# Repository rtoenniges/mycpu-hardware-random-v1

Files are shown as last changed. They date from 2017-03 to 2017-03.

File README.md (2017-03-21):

# MyCPU_HDW_RandomV1
A hardware random number generator for the [MyCPU](http://www.mycpu.eu/) based on the work of [Aaron Logue](http://www.cryogenius.com/hardware/rng/).

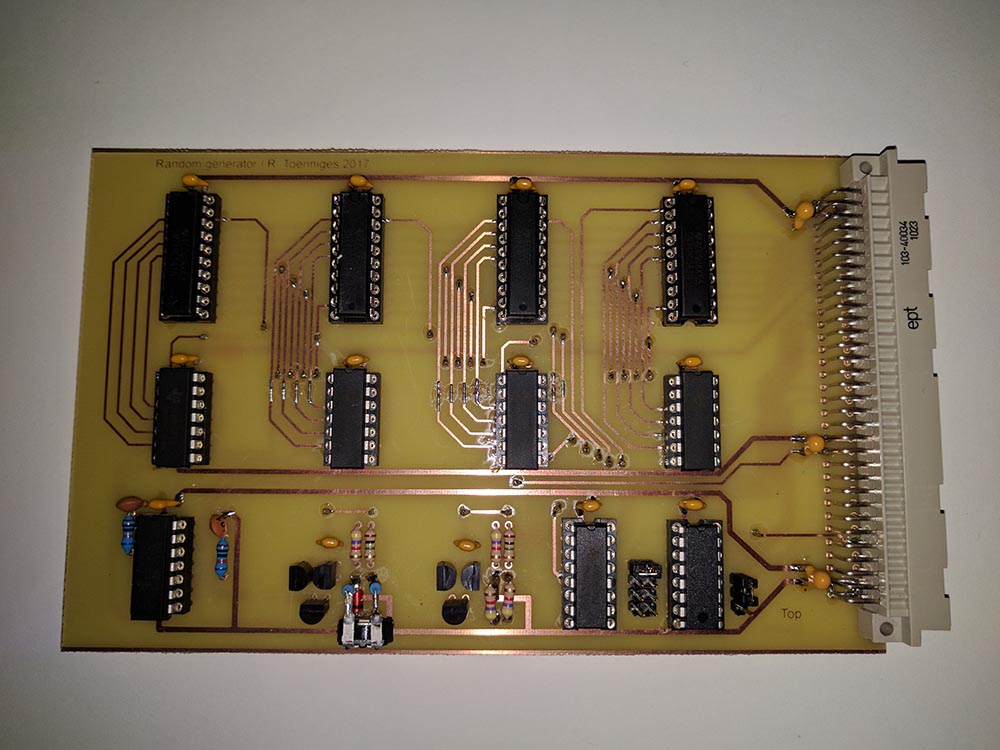
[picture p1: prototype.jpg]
Picture of the prototype The first prototype


## Applications
* Games
* Math programs
* Encryption

## Features
* Address selectable through jumpers
* Two independent noise generators
* Both noise generators were adjustable through trimmers (For justage please use this [software](/hist_prg))
* Generates 2x 16bit random numbers simultaneously
* Fetch frequenz about 1MHz (means a new random number every ~16µs)

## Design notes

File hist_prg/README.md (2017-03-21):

# Software - Random histogram

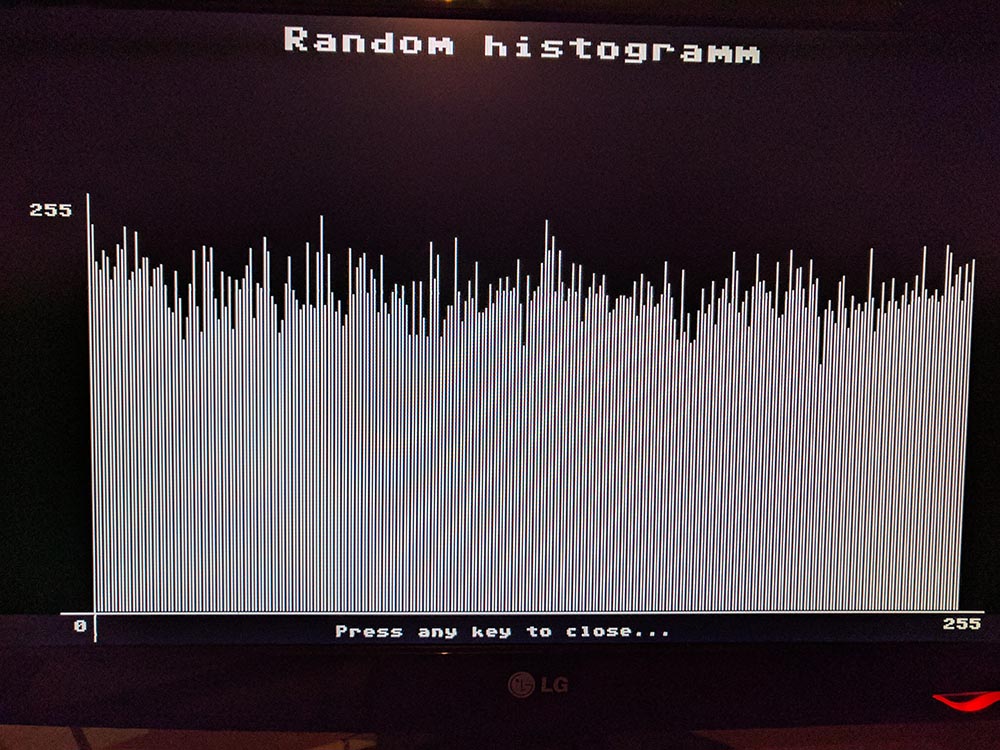
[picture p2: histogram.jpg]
Picture of a histogramm Histogram created by 'random_histo'


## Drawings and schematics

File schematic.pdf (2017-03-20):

# 74HC139N VCC

GND ¹⁰⁰n | 10u 100n 100n 100n 100n 100n 100n 100n 100n 100n 100n | 10u 10u | +12V VCC

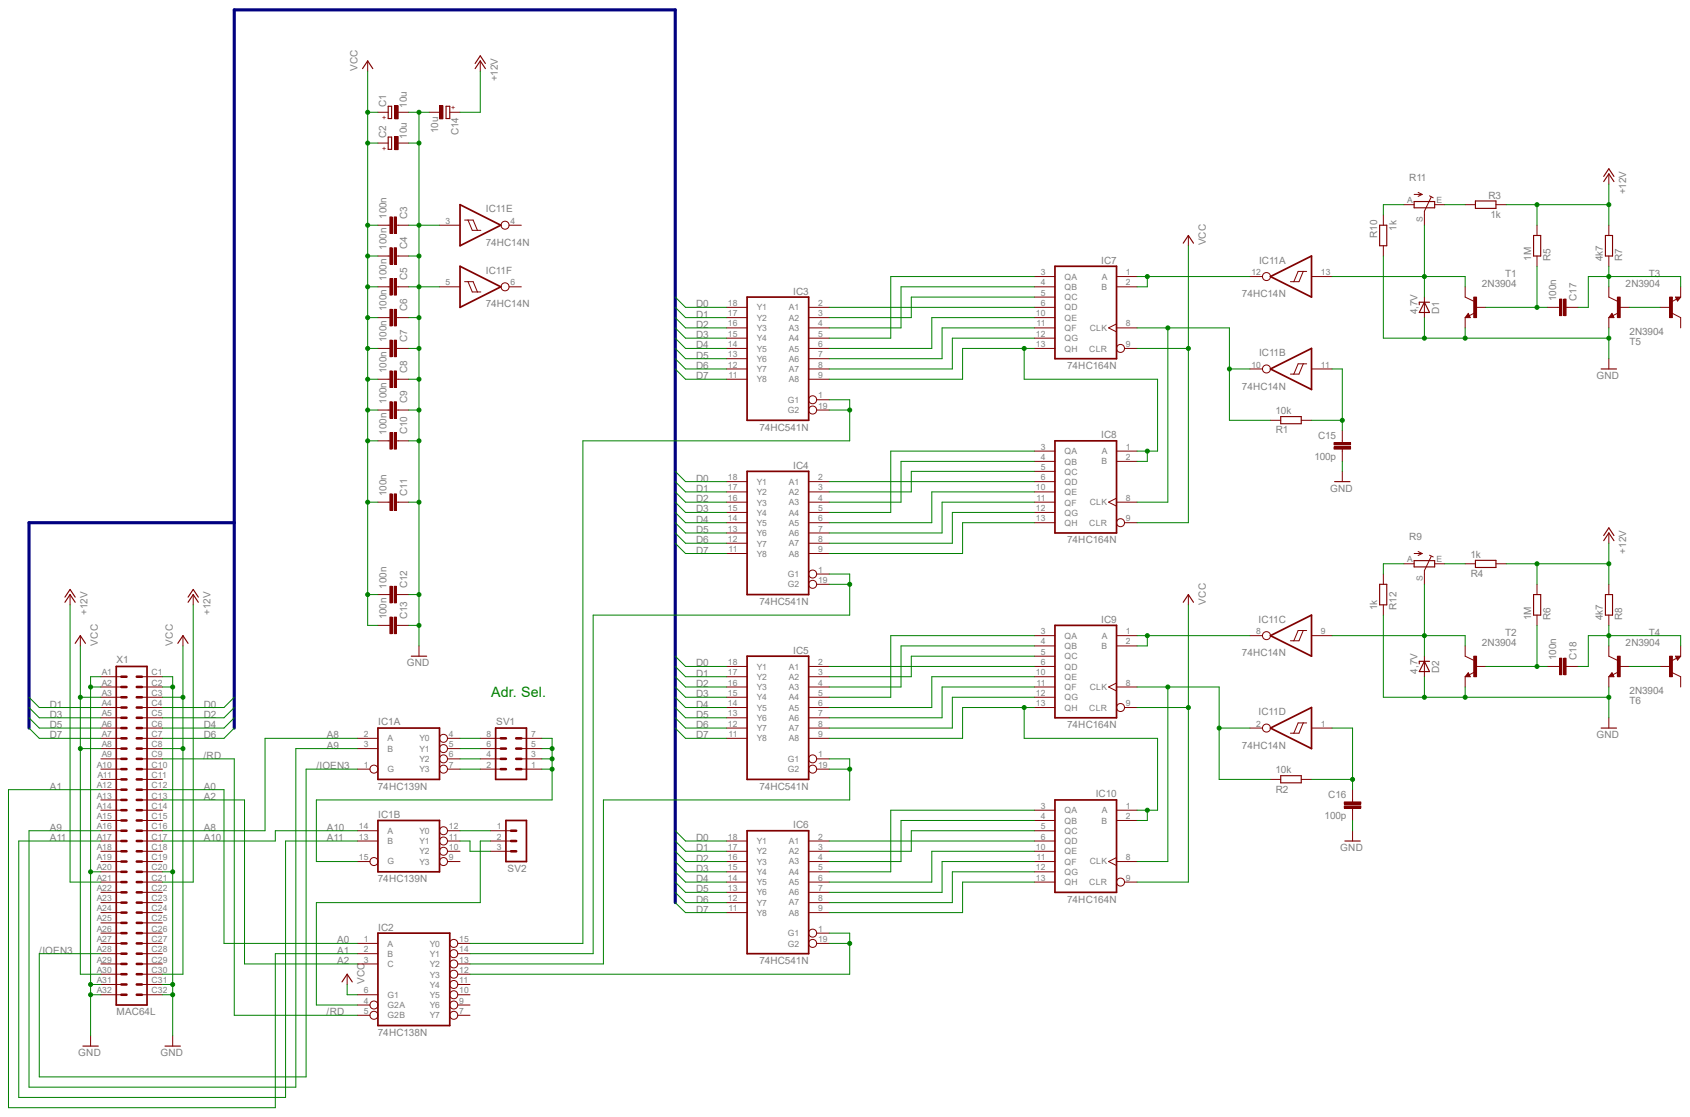
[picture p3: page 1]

3 | QE 10
4 | QF 11

A31 | C31
A32 | C32

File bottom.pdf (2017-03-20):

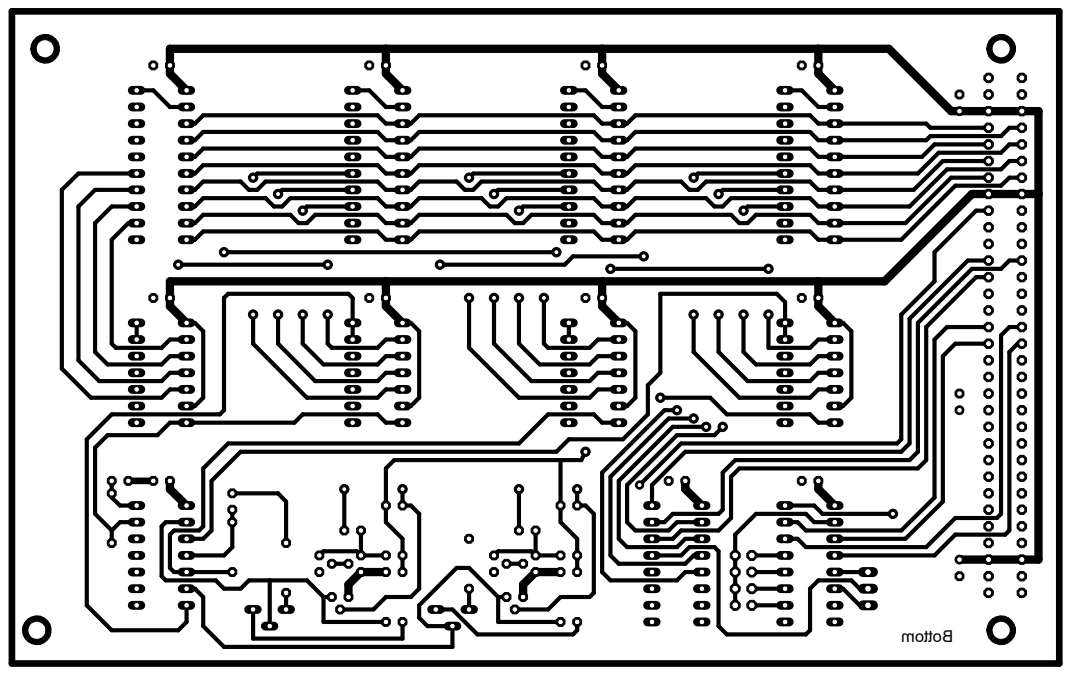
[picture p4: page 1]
Bottom

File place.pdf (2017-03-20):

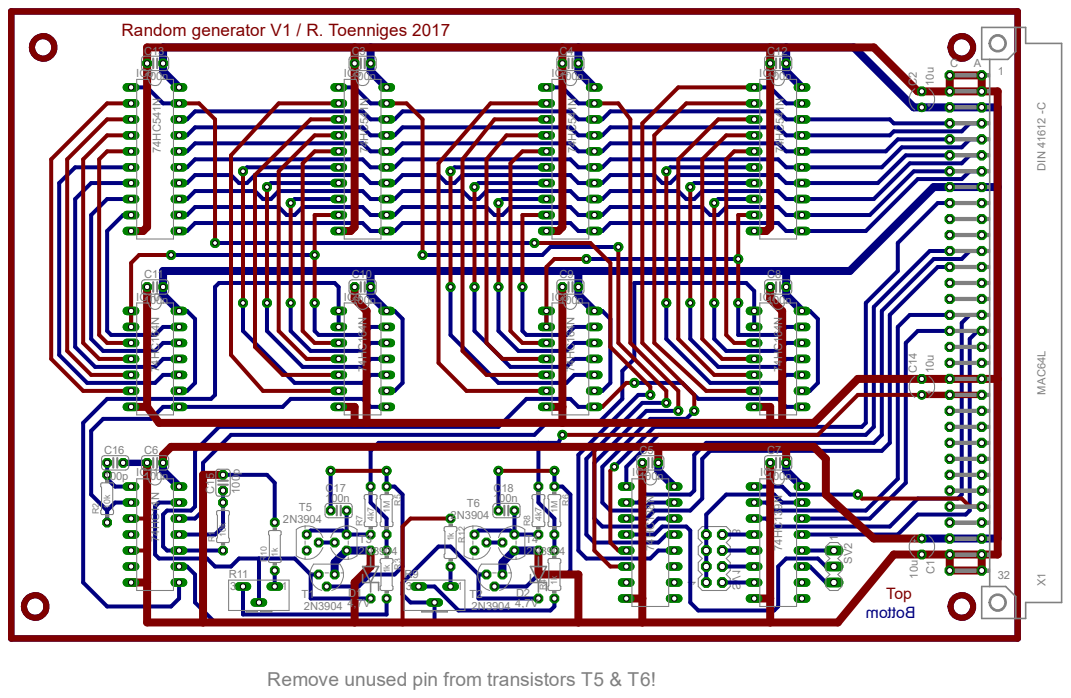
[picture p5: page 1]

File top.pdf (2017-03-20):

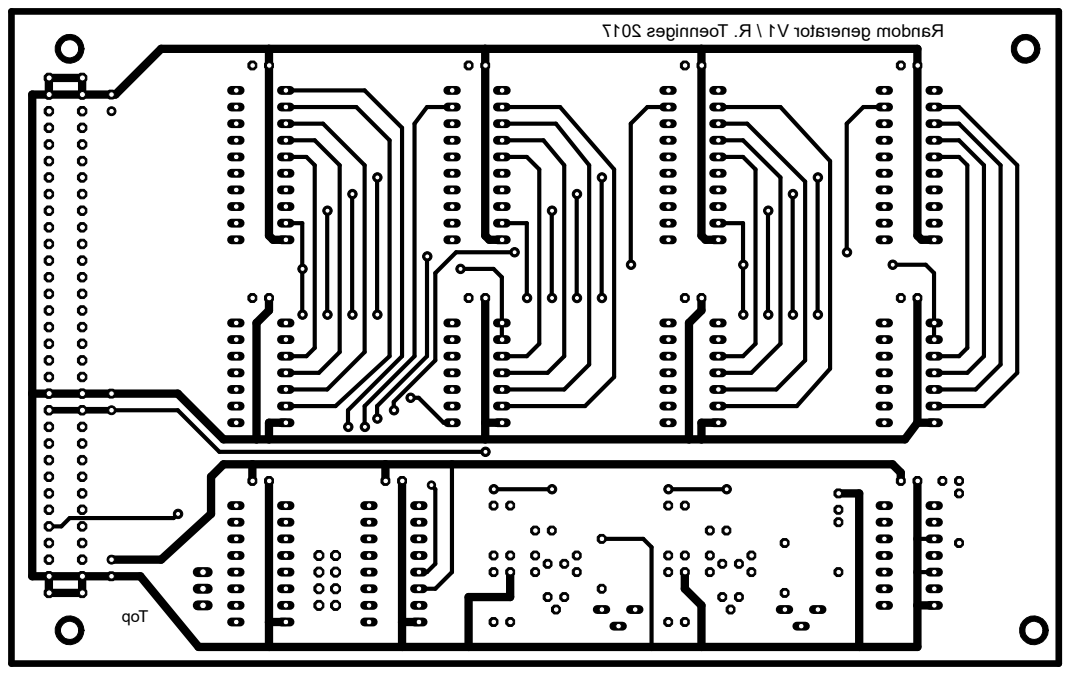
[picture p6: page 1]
Top

Random generator V1 / R. Toenniges 2017

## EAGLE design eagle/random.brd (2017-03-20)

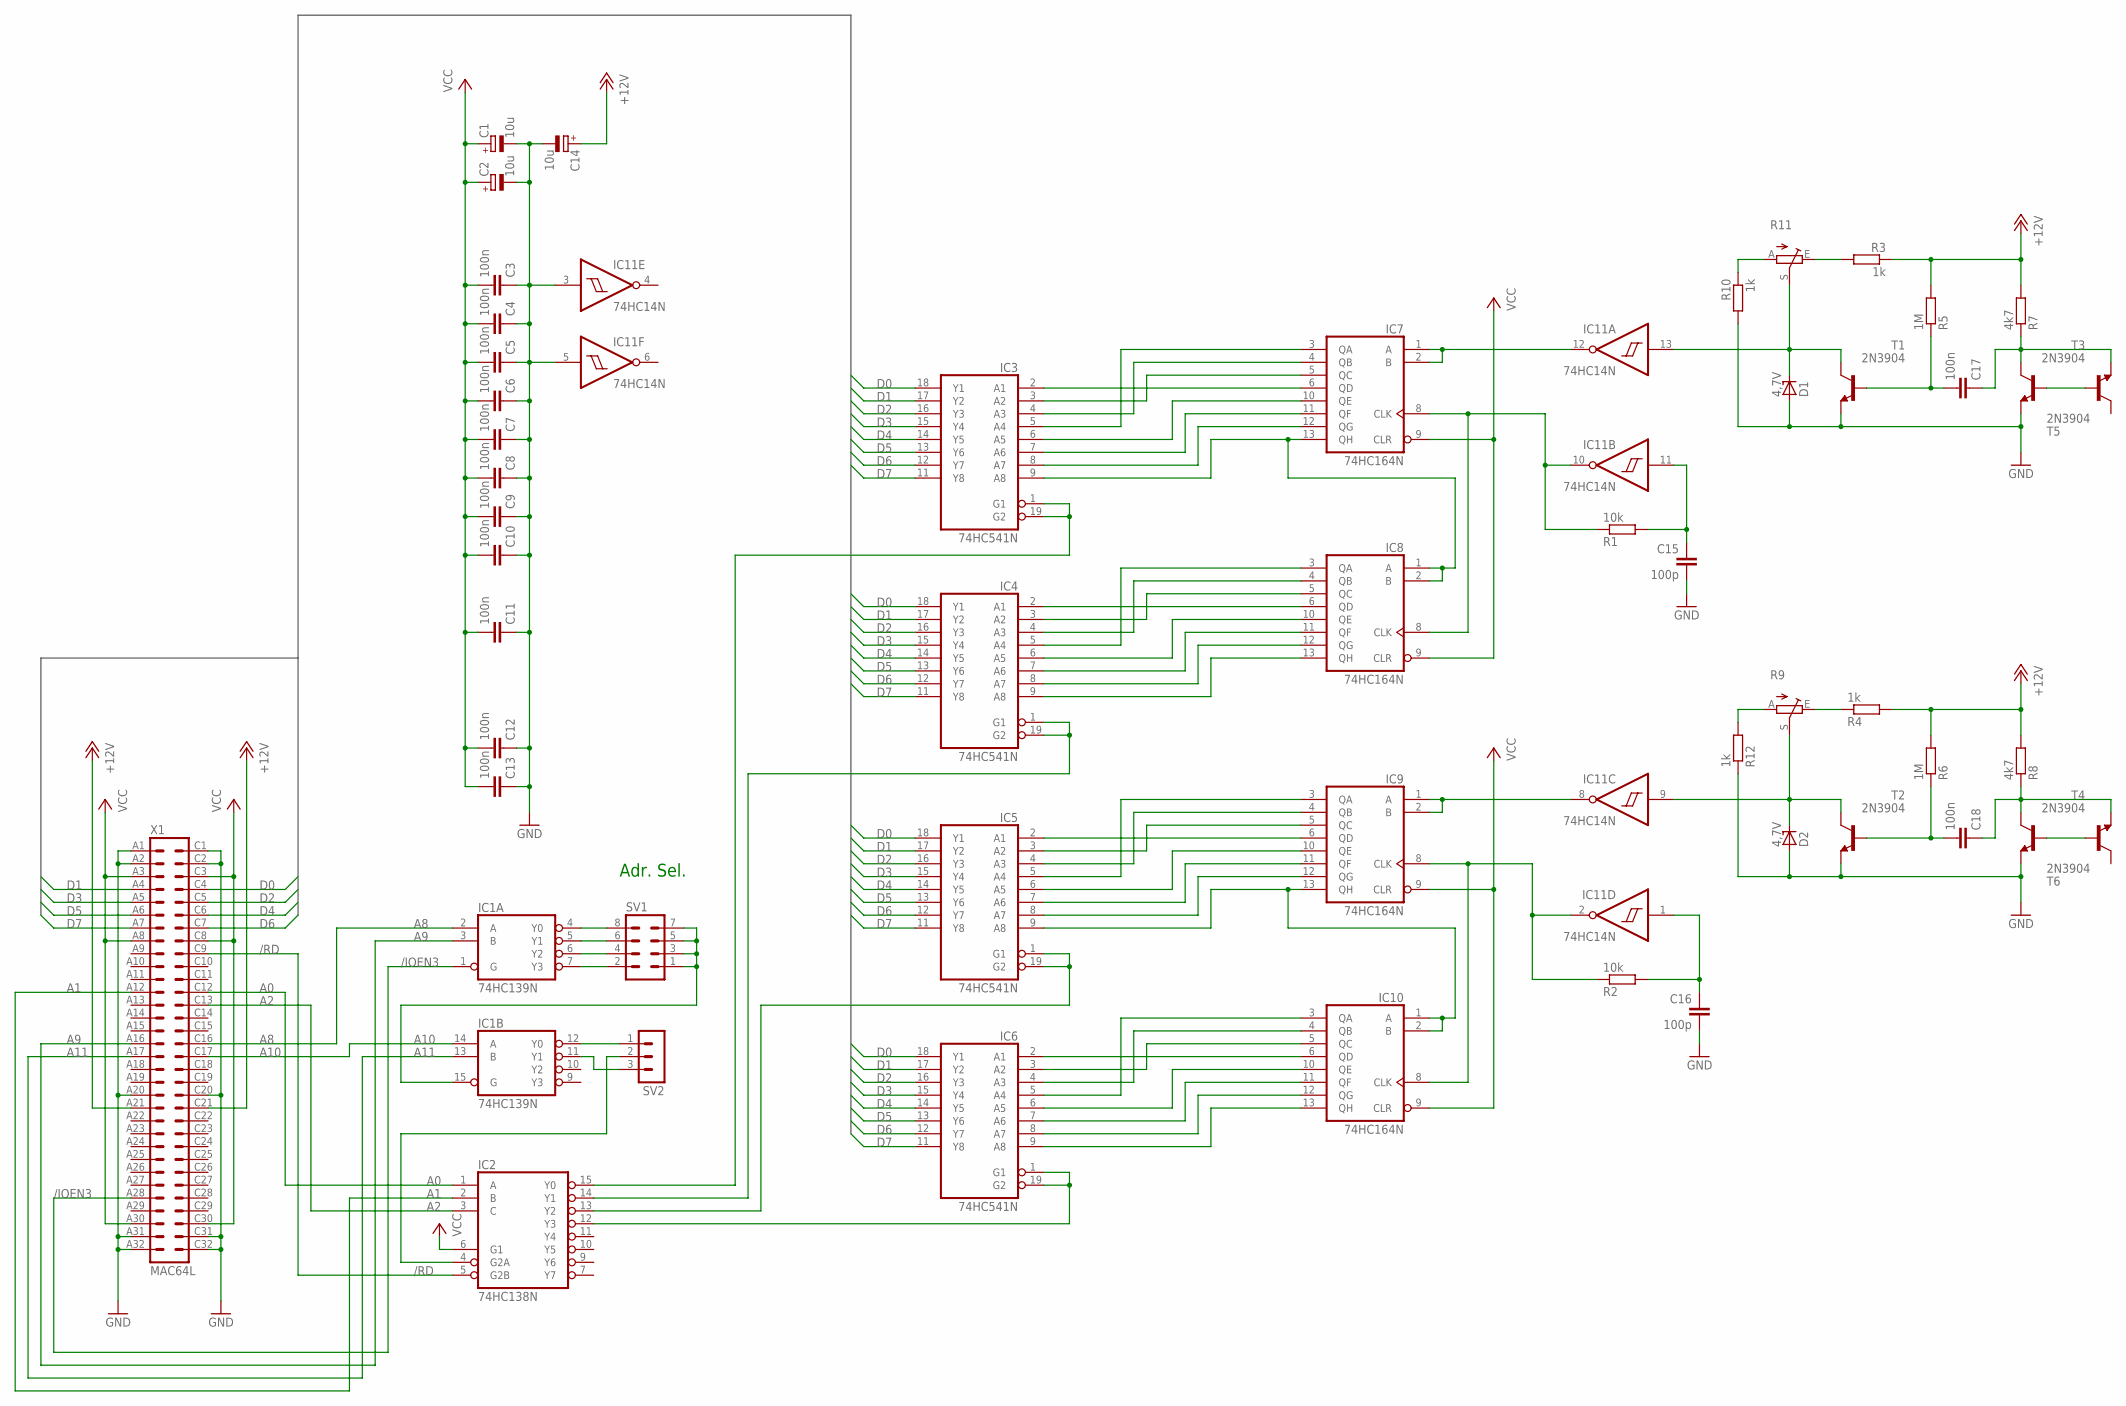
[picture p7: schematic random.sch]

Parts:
C1, C2, C14: 10u; TT2D4
C3, C4, C5, C6, C7, C8, C9, C10, C11, C12, C13, C17, C18: 100n; C025-024X044
C15, C16: 100p; C025-024X044
D1, D2: 4,7V; ZDIO-7.5
IC1: 74HC139N; DIL16
IC2: 74HC138N; DIL16
IC3, IC4, IC5, IC6: 74HC541N; DIL20
IC7, IC8, IC9, IC10: 74HC164N; DIL14
IC11: 74HC14N; DIL14
R1, R2: 10k; 0204/7
R3, R4, R10, R12: 1k; 0204/7
R5, R6: 1M; 0204/7
R7, R8: 4k7; 0204/7
R9, R11: TRIM_EU-S63X; S63X
SV1: MA04-2
SV2: MA03-1
T1, T2, T3, T4, T5, T6: 2N3904; TO92
X1: MAC64L

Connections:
+12V: C14.+, R3.1, R4.2, R5.2, R6.2, R7.2, R8.2, X1.A21, X1.C21
/IOEN3: IC1.1 (G), X1.A28
/RD: IC2.5 (G2B), X1.C9
A0: IC2.1 (A), X1.C12
A1: IC2.2 (B), X1.A12
A2: IC2.3 (C), X1.C13
A8: IC1.2 (A), X1.C16
A9: IC1.3 (B), X1.A16
A10: IC1.14 (A), X1.C17
A11: IC1.13 (B), X1.A17
D0: IC3.18 (Y1), IC4.18 (Y1), IC5.18 (Y1), IC6.18 (Y1), X1.C4
D1: IC3.17 (Y2), IC4.17 (Y2), IC5.17 (Y2), IC6.17 (Y2), X1.A4
D2: IC3.16 (Y3), IC4.16 (Y3), IC5.16 (Y3), IC6.16 (Y3), X1.C5
D3: IC3.15 (Y4), IC4.15 (Y4), IC5.15 (Y4), IC6.15 (Y4), X1.A5
D4: IC3.14 (Y5), IC4.14 (Y5), IC5.14 (Y5), IC6.14 (Y5), X1.C6
D5: IC3.13 (Y6), IC4.13 (Y6), IC5.13 (Y6), IC6.13 (Y6), X1.A6
D6: IC3.12 (Y7), IC4.12 (Y7), IC5.12 (Y7), IC6.12 (Y7), X1.C7
D7: IC3.11 (Y8), IC4.11 (Y8), IC5.11 (Y8), IC6.11 (Y8), X1.A7
GND: C1.-, C2.-, C3.1, C4.1, C5.1, C6.1, C7.1, C8.1, C9.1, C10.1, C11.1, C12.1, C13.1, C14.-, C15.2, C16.2, D1.A, D2.A, IC1.8 (GND), IC2.8 (GND), IC3.10 (GND), IC4.10 (GND), IC5.10 (GND), IC6.10 (GND), IC7.7 (GND), IC8.7 (GND), IC9.7 (GND), IC10.7 (GND), IC11.3 (I), IC11.5 (I), IC11.7 (GND), R10.2, R12.1, T1.3 (E), T2.3 (E), T3.3 (E), T4.3 (E), X1.A1, X1.A2, X1.A20, X1.A31, X1.A32, X1.C1, X1.C2, X1.C20, X1.C31, X1.C32
unnamed: T3.2 (B), T5.2 (B)
unnamed: C17.1, R7.1, T3.1 (C), T5.3 (E)
unnamed: C17.2, R5.1, T1.2 (B)
unnamed: D1.C, IC11.13 (I), R11.S, T1.1 (C)
unnamed: T4.2 (B), T6.2 (B)
unnamed: C18.1, R8.1, T4.1 (C), T6.3 (E)
unnamed: C18.2, R6.1, T2.2 (B)
unnamed: D2.C, IC11.9 (I), R9.S, T2.1 (C)
unnamed: C16.1, IC11.1 (I), R2.2
unnamed: IC7.8 (CLK), IC8.8 (CLK), IC11.10 (O), R1.1
unnamed: C15.1, IC11.11 (I), R1.2
unnamed: IC9.1 (A), IC9.2 (B), IC11.8 (O)
unnamed: IC5.9 (A8), IC9.13 (QH), IC10.1 (A), IC10.2 (B)
unnamed: R3.2, R11.E
unnamed: R10.1, R11.A
unnamed: R4.1, R9.E
unnamed: R9.A, R12.2
unnamed: IC5.2 (A1), IC9.6 (QD)
unnamed: IC5.3 (A2), IC9.5 (QC)
unnamed: IC7.1 (A), IC7.2 (B), IC11.12 (O)
unnamed: IC3.9 (A8), IC7.13 (QH), IC8.1 (A), IC8.2 (B)
unnamed: IC5.4 (A3), IC9.4 (QB)
unnamed: IC3.8 (A7), IC7.12 (QG)
unnamed: IC3.7 (A6), IC7.11 (QF)
unnamed: IC3.6 (A5), IC7.10 (QE)
unnamed: IC3.2 (A1), IC7.6 (QD)
unnamed: IC3.3 (A2), IC7.5 (QC)
unnamed: IC3.4 (A3), IC7.4 (QB)
unnamed: IC4.2 (A1), IC8.6 (QD)
unnamed: IC4.3 (A2), IC8.5 (QC)
unnamed: IC4.4 (A3), IC8.4 (QB)
unnamed: IC4.5 (A4), IC8.3 (QA)
unnamed: IC4.6 (A5), IC8.10 (QE)
unnamed: IC4.7 (A6), IC8.11 (QF)
unnamed: IC4.8 (A7), IC8.12 (QG)
unnamed: IC4.9 (A8), IC8.13 (QH)
unnamed: IC5.5 (A4), IC9.3 (QA)
unnamed: IC5.6 (A5), IC9.10 (QE)
unnamed: IC9.8 (CLK), IC10.8 (CLK), IC11.2 (O), R2.1
unnamed: IC5.7 (A6), IC9.11 (QF)
unnamed: IC5.8 (A7), IC9.12 (QG)
unnamed: IC6.2 (A1), IC10.6 (QD)
unnamed: IC6.3 (A2), IC10.5 (QC)
unnamed: IC6.4 (A3), IC10.4 (QB)
unnamed: IC6.5 (A4), IC10.3 (QA)
unnamed: IC6.6 (A5), IC10.10 (QE)
unnamed: IC6.7 (A6), IC10.11 (QF)
unnamed: IC6.8 (A7), IC10.12 (QG)
unnamed: IC6.9 (A8), IC10.13 (QH)
unnamed: IC1.15 (G), SV1.1, SV1.3, SV1.5, SV1.7
unnamed: IC1.4 (Y0), SV1.8
unnamed: IC1.5 (Y1), SV1.6
unnamed: IC1.6 (Y2), SV1.4
unnamed: IC1.7 (Y3), SV1.2
unnamed: IC1.12 (Y0), SV2.1
unnamed: IC1.11 (Y1), SV2.3
unnamed: IC2.4 (G2A), SV2.2
unnamed: IC2.15 (Y0), IC3.1 (G1), IC3.19 (G2)
unnamed: IC2.14 (Y1), IC4.1 (G1), IC4.19 (G2)
unnamed: IC2.13 (Y2), IC5.1 (G1), IC5.19 (G2)
unnamed: IC2.12 (Y3), IC6.1 (G1), IC6.19 (G2)
unnamed: IC3.5 (A4), IC7.3 (QA)
VCC: C1.+, C2.+, C3.2, C4.2, C5.2, C6.2, C7.2, C8.2, C9.2, C10.2, C11.2, C12.2, C13.2, IC1.16 (VCC), IC2.6 (G1), IC2.16 (VCC), IC3.20 (VCC), IC4.20 (VCC), IC5.20 (VCC), IC6.20 (VCC), IC7.9 (CLR), IC7.14 (VCC), IC8.9 (CLR), IC8.14 (VCC), IC9.9 (CLR), IC9.14 (VCC), IC10.9 (CLR), IC10.14 (VCC), IC11.14 (VCC), X1.A3, X1.A8, X1.A30, X1.C3, X1.C8, X1.C30

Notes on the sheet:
Adr. Sel.

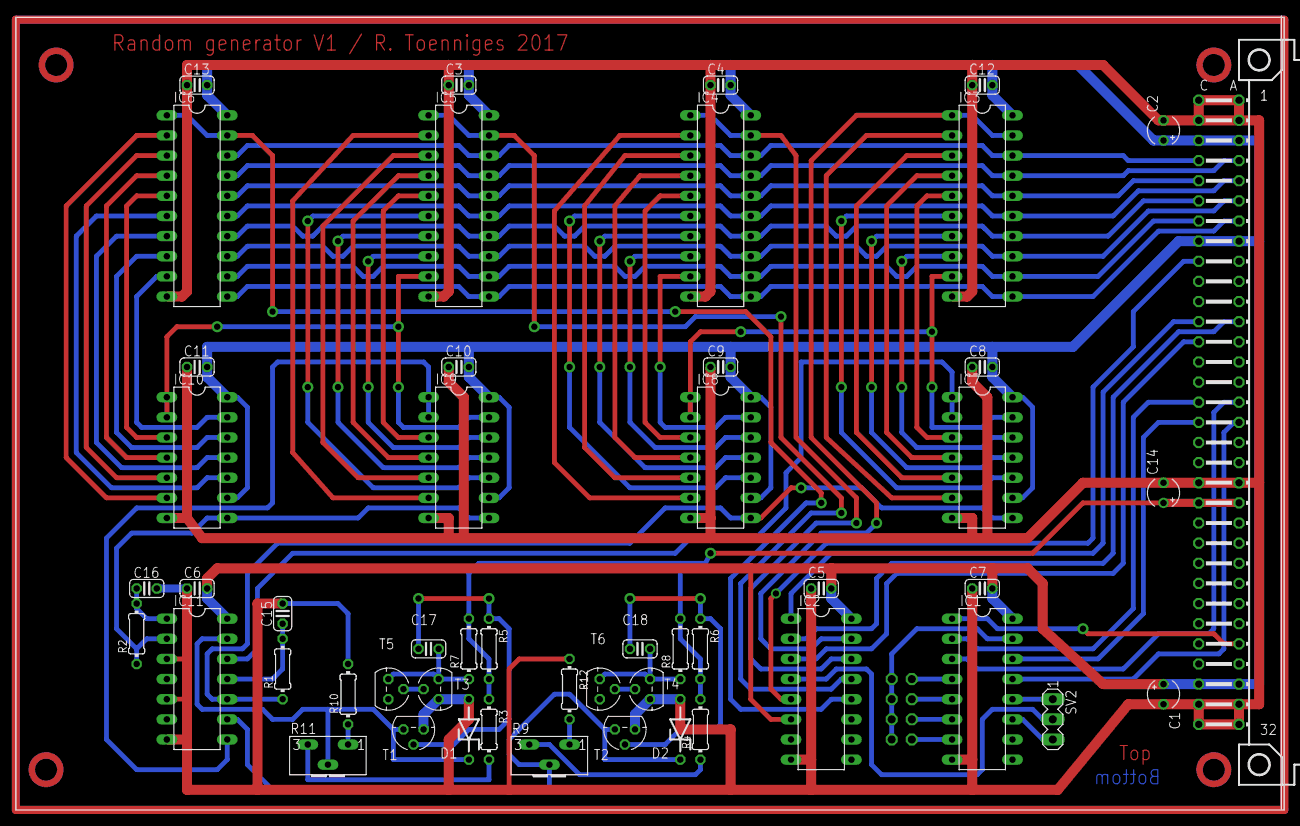
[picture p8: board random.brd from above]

Board: 2 copper layers, 160.0 x 100.0 mm, 52 parts (1 on the bottom side), 82 nets.

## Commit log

2017-03-20 Initial upload
    [jumper.xlsx, random.brd, random.sch]
2017-03-20 Remove files
    [jumper.xlsx]
2017-03-20 Updated layout
    [random.brd]
